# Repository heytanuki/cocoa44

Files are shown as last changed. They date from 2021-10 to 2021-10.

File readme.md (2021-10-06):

# 44% Cocoa

A choc-spaced, splittable 40 with hazard stripes across the top.

The 44% Cocoa was designed and sized to be under the 100mm^2 limit for free fabrication thru Allpcb. It is a little wider than 100mm wide, but that didn't seem to affect it being free!

### One small issue...

This has mounting holes directly under the top-left and top-right switches. What that means is that likely you will need to either use countersunk screws on those holes (the kind that have a conical head shape that's wider at the top), or change the size of the board to move those holes out to the side.

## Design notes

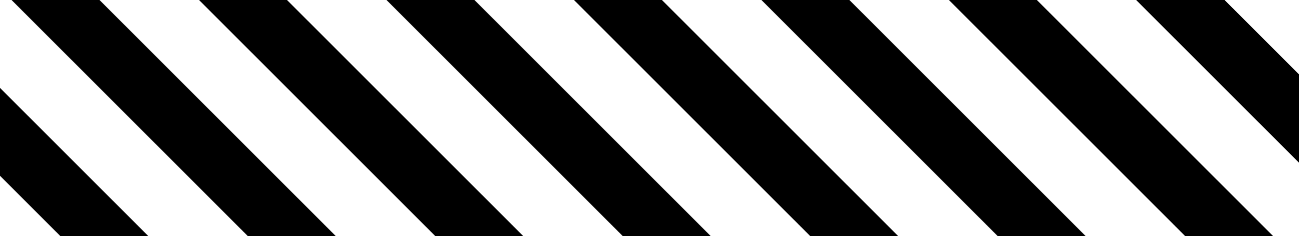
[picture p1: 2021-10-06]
top_stripes.png

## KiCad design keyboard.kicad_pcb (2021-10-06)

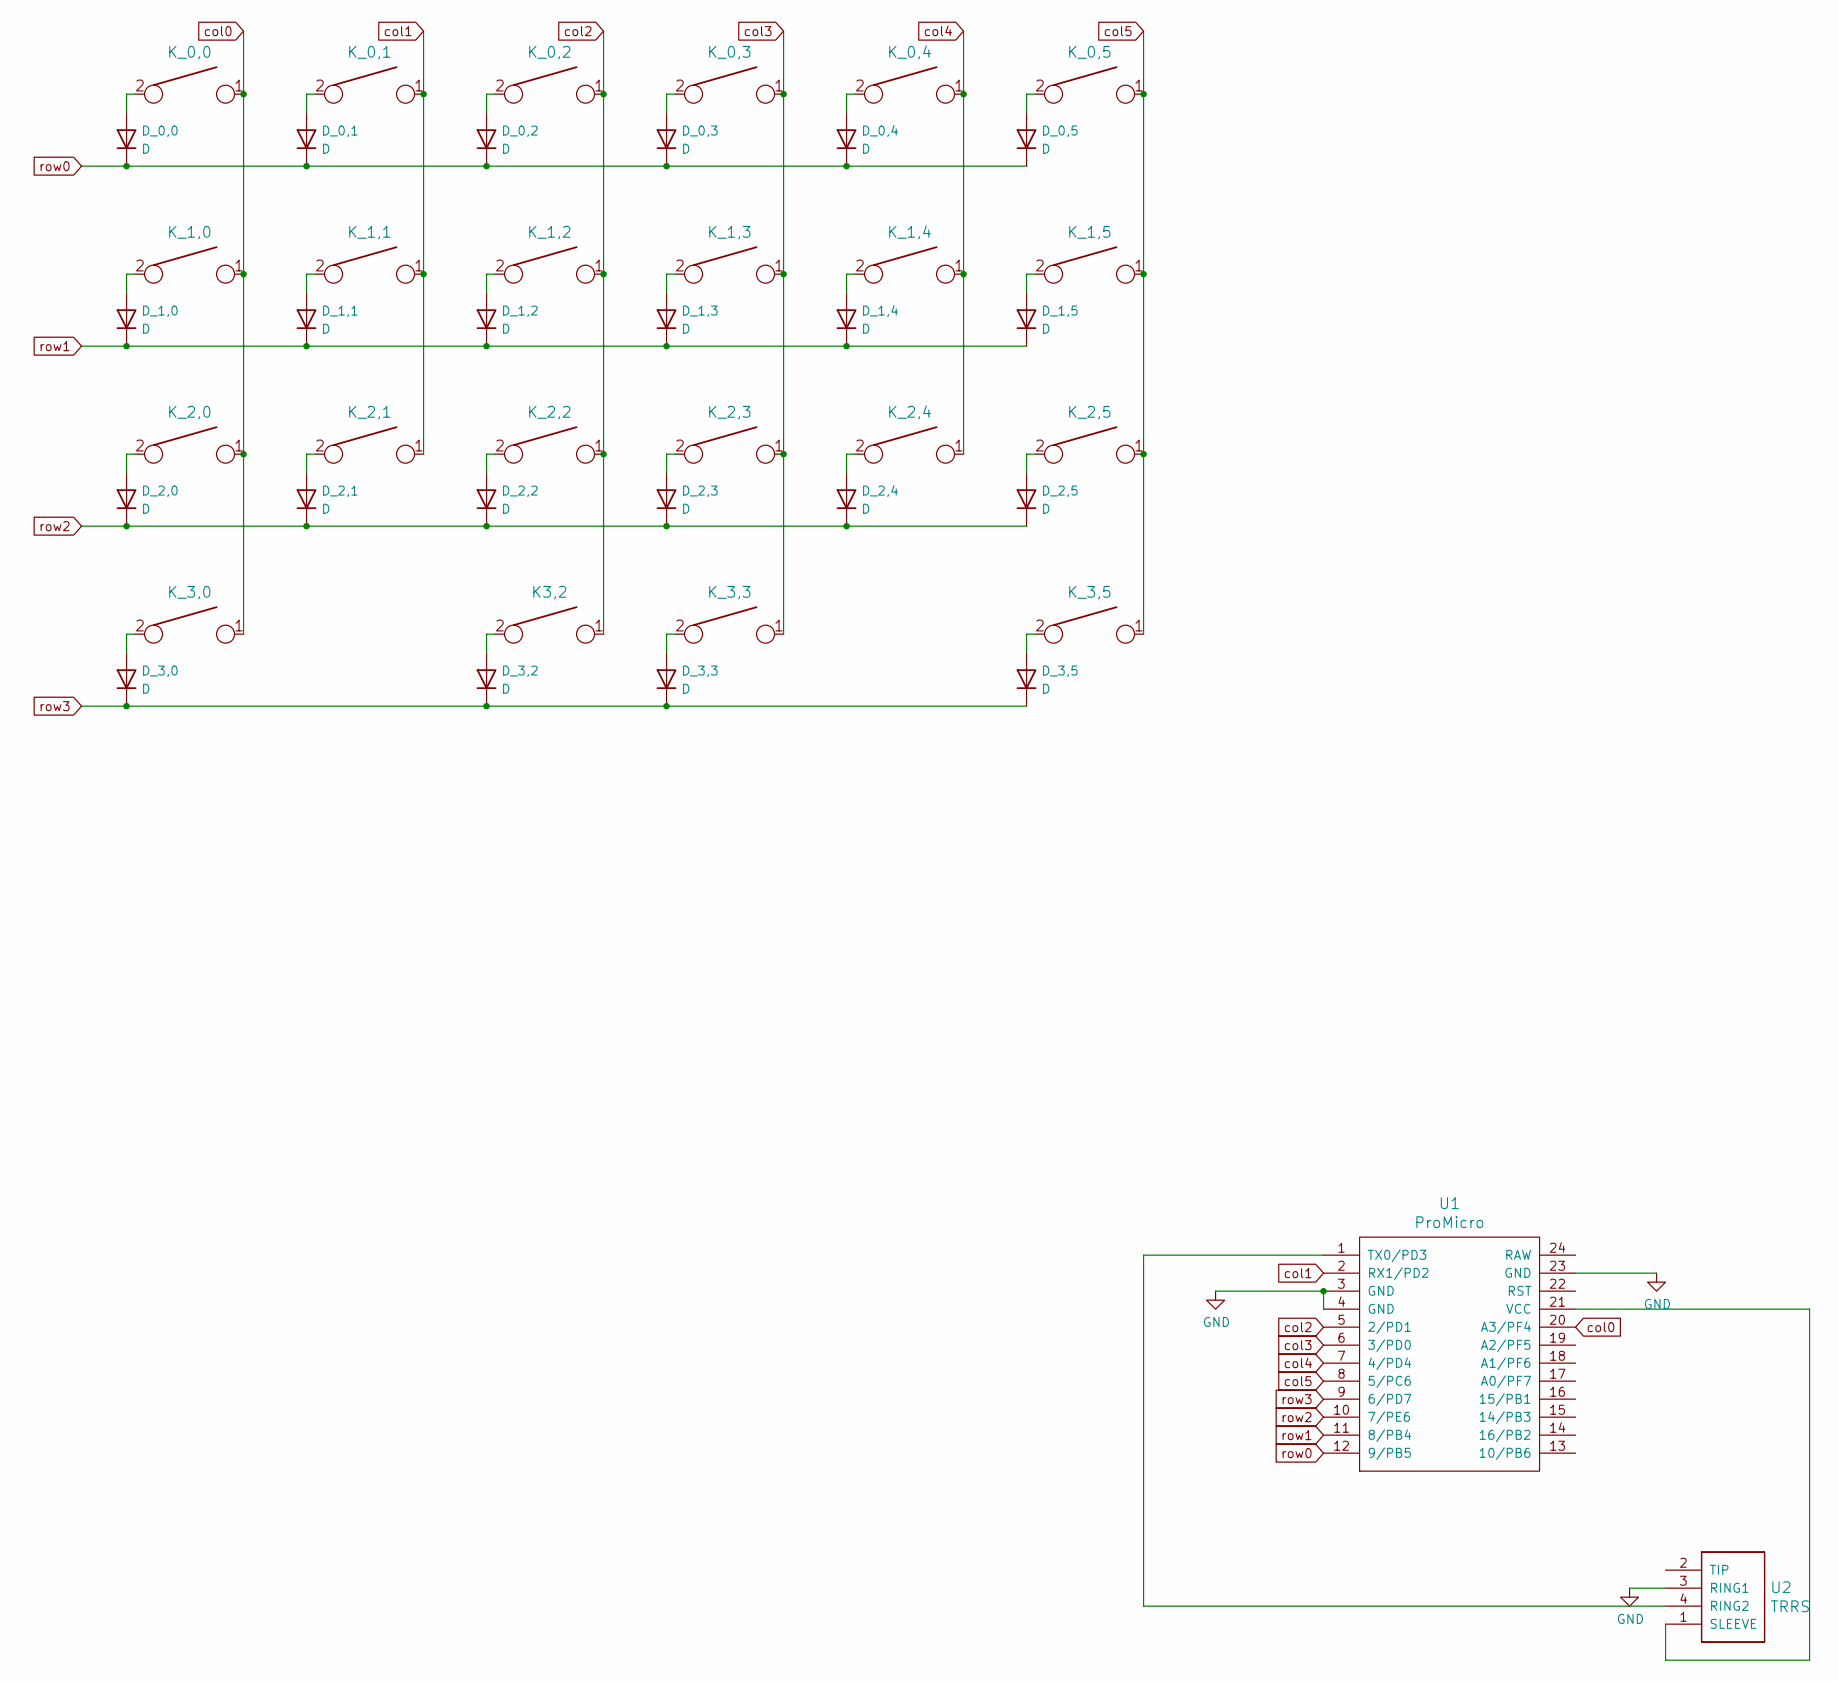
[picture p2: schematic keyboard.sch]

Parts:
D_0,0, D_0,1, D_0,2, D_0,3, D_0,4, D_0,5, D_1,0, D_1,1, D_1,2, D_1,3, D_1,4, D_1,5, D_2,0, D_2,1, D_2,2, D_2,3, D_2,4, D_2,5, D_3,0, D_3,2, D_3,3, D_3,5: D; D_SOD123_axial
K3,2: KEYSW; Choc-1u
K_0,0, K_0,1, K_0,2, K_0,3, K_0,4, K_0,5, K_1,0, K_1,1, K_1,2, K_1,3, K_1,4, K_1,5, K_2,0, K_2,1, K_2,2, K_2,3, K_2,4, K_2,5, K_3,3: KEYSW; Choc-1u
K_3,0, K_3,5: KEYSW; Choc-2u
U1: ProMicro; ArduinoProMicro
U2: TRRS; TRRS-PJ-320A

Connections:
GND: U1.3 (GND), U1.4 (GND), U1.23 (GND), U2.3 (RING1)
unnamed: D_0,0.2 (A), K_0,0.2
unnamed: D_0,1.2 (A), K_0,1.2
unnamed: D_0,2.2 (A), K_0,2.2
unnamed: D_0,3.2 (A), K_0,3.2
unnamed: D_0,4.2 (A), K_0,4.2
unnamed: D_0,5.2 (A), K_0,5.2
unnamed: D_1,0.2 (A), K_1,0.2
unnamed: D_1,1.2 (A), K_1,1.2
unnamed: D_1,2.2 (A), K_1,2.2
unnamed: D_1,3.2 (A), K_1,3.2
unnamed: D_1,4.2 (A), K_1,4.2
unnamed: D_1,5.2 (A), K_1,5.2
unnamed: D_2,0.2 (A), K_2,0.2
unnamed: D_2,1.2 (A), K_2,1.2
unnamed: D_2,2.2 (A), K_2,2.2
unnamed: D_2,3.2 (A), K_2,3.2
unnamed: D_2,4.2 (A), K_2,4.2
unnamed: D_2,5.2 (A), K_2,5.2
unnamed: D_3,0.2 (A), K_3,0.2
unnamed: D_3,2.2 (A), K3,2.2
unnamed: D_3,3.2 (A), K_3,3.2
unnamed: D_3,5.2 (A), K_3,5.2
unnamed: U1.1 (TX0/PD3), U2.4 (RING2)
unnamed: U1.21 (VCC), U2.1 (SLEEVE)
col0: K_0,0.1, K_1,0.1, K_2,0.1, K_3,0.1, U1.20 (A3/PF4)
col1: K_0,1.1, K_1,1.1, K_2,1.1, U1.2 (RX1/PD2)
col2: K3,2.1, K_0,2.1, K_1,2.1, K_2,2.1, U1.5 (2/PD1)
col3: K_0,3.1, K_1,3.1, K_2,3.1, K_3,3.1, U1.6 (3/PD0)
col4: K_0,4.1, K_1,4.1, K_2,4.1, U1.7 (4/PD4)
col5: K_0,5.1, K_1,5.1, K_2,5.1, K_3,5.1, U1.8 (5/PC6)
row0: D_0,0.1 (K), D_0,1.1 (K), D_0,2.1 (K), D_0,3.1 (K), D_0,4.1 (K), D_0,5.1 (K), U1.12 (9/PB5)
row1: D_1,0.1 (K), D_1,1.1 (K), D_1,2.1 (K), D_1,3.1 (K), D_1,4.1 (K), D_1,5.1 (K), U1.11 (8/PB4)
row2: D_2,0.1 (K), D_2,1.1 (K), D_2,2.1 (K), D_2,3.1 (K), D_2,4.1 (K), D_2,5.1 (K), U1.10 (7/PE6)
row3: D_3,0.1 (K), D_3,2.1 (K), D_3,3.1 (K), D_3,5.1 (K), U1.9 (6/PD7)

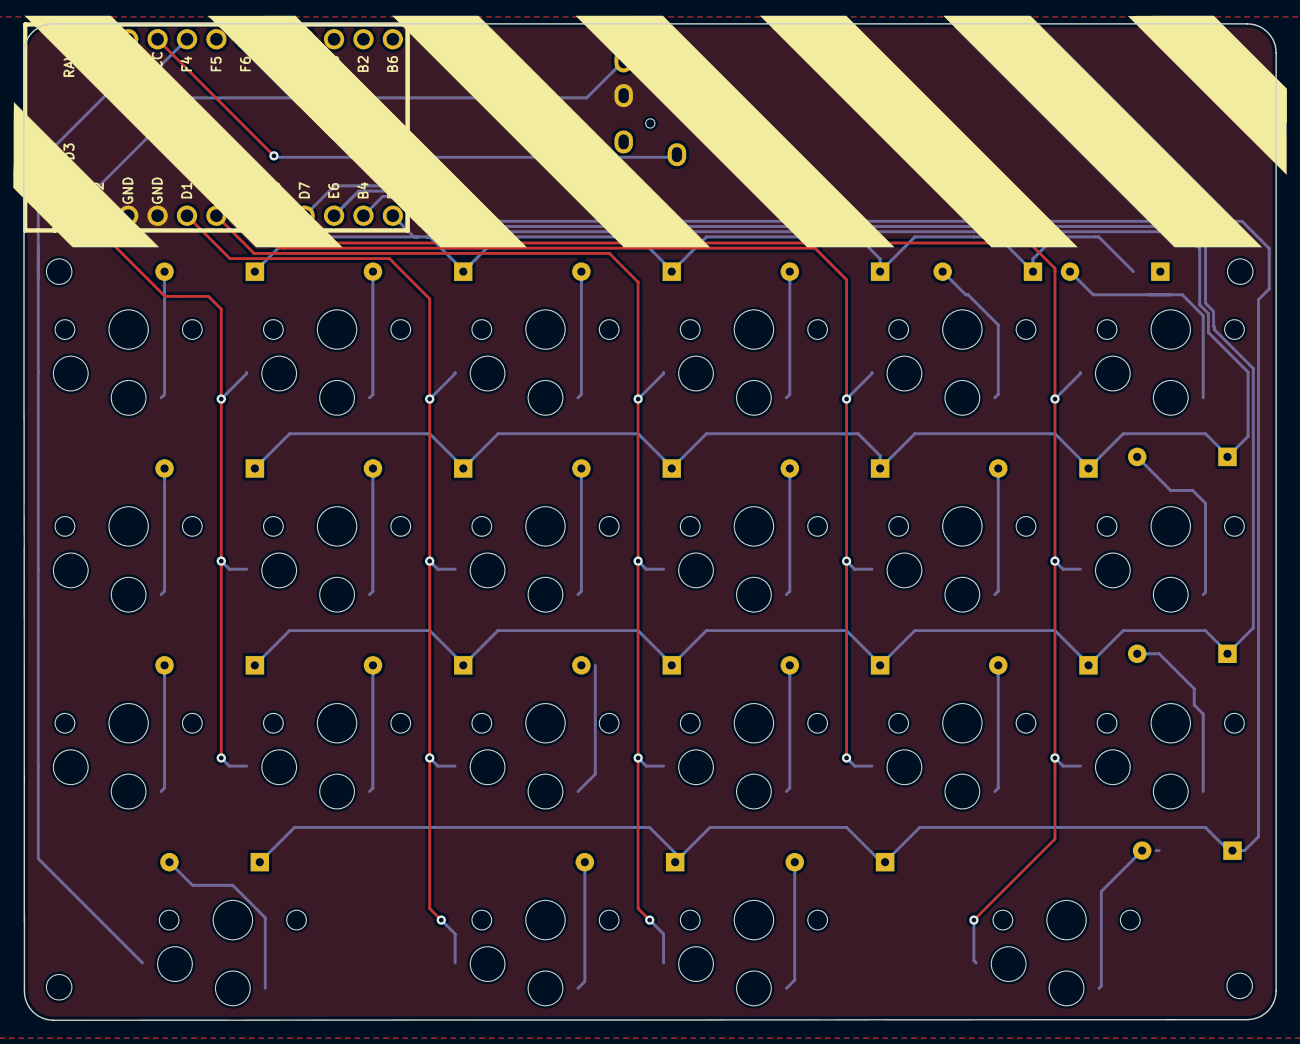
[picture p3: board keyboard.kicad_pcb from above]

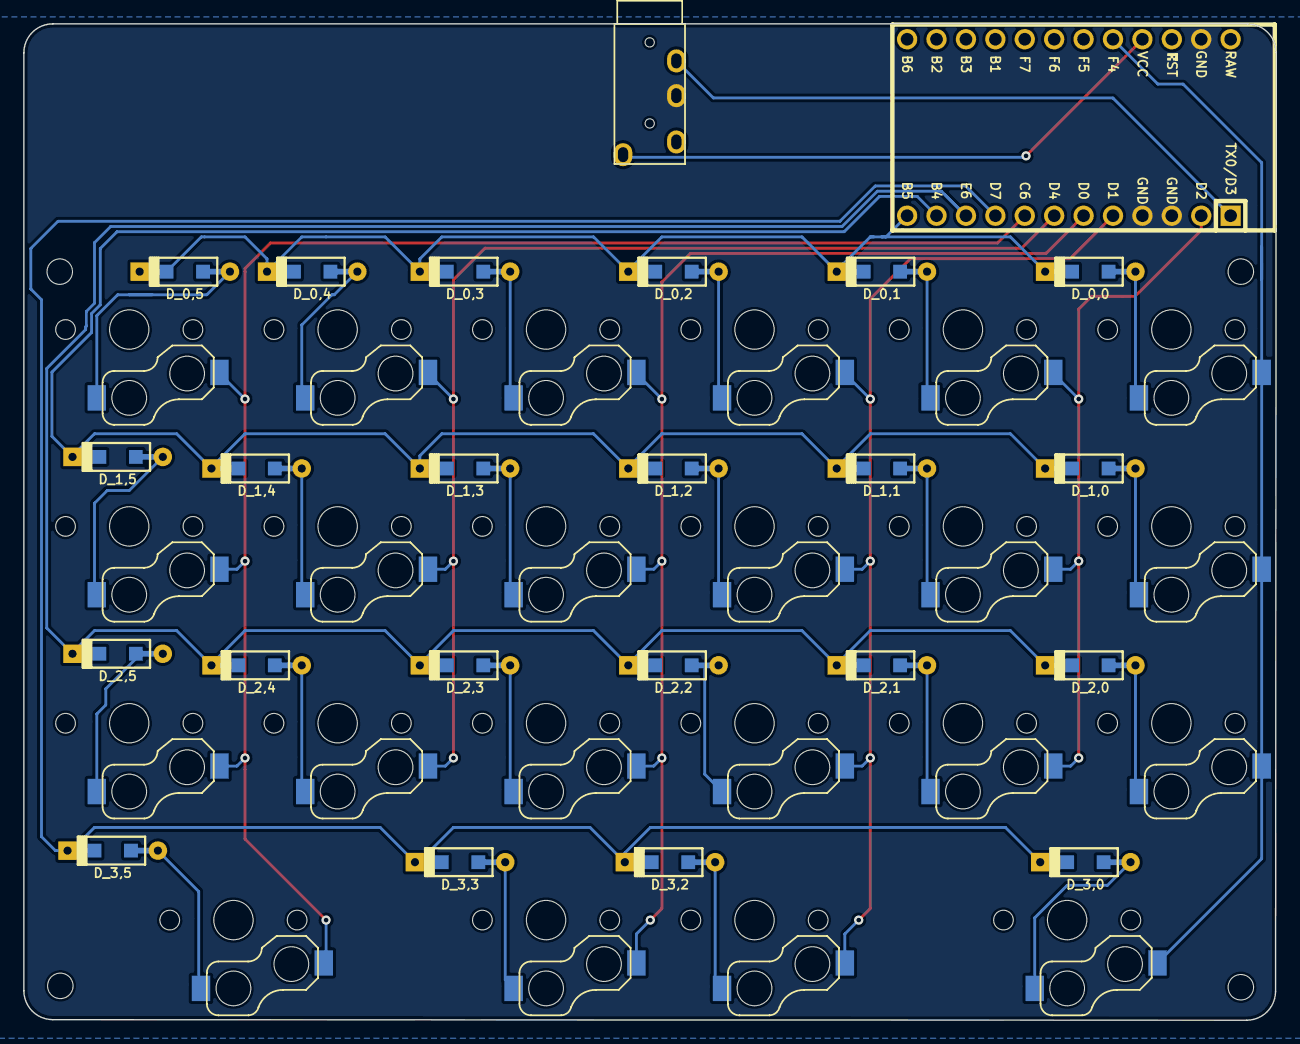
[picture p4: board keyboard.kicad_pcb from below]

Board: 2 copper layers, 108.1 x 86.1 mm, 46 parts (23 on the bottom side), 35 nets.

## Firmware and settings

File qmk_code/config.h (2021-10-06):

/*
Copyright 2021 Astra Jones

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
You should have received a copy of the GNU General Public License
along with this program.  If not, see <http://www.gnu.org/licenses/>.
*/

#pragma once

#include "config_common.h"

/* USB Device descriptor parameter */
#define VENDOR_ID       0x2605
#define PRODUCT_ID      0x44CC
#define DEVICE_VER      0x0002
#define MANUFACTURER    Star Boards
#define PRODUCT         44% Cocoa
#define DESCRIPTION     40 ortho split with choc spacing
#define VIAL_KEYBOARD_UID {0xF5, 0xF7, 0xCC, 0xD4, 0xEE, 0xED, 0x00, 0x1D}
 
/* key matrix size */
#define MATRIX_ROWS 8
#define MATRIX_COLS 6

#define SOFT_SERIAL_PIN D3
#define SPLIT_USB_DETECT

/*
 * Keyboard Matrix Assignments
 *
 * Change this to how you wired your keyboard
 * COLS: AVR pins used for columns, left to right
 * ROWS: AVR pins used for rows, top to bottom
 * DIODE_DIRECTION: COL2ROW = COL = Anode (+), ROW = Cathode (-, marked on diode)
 *                  ROW2COL = ROW = Anode (+), COL = Cathode (-, marked on diode)
 *
*//////////////////
#define MATRIX_ROW_PINS { B5, B4, E6, D7 }
#define MATRIX_COL_PINS { F4, D2, D1, D0, D4, C6 }

/* COL2ROW, ROW2COL*/
#define DIODE_DIRECTION COL2ROW

/* Debounce reduces chatter (unintended double-presses) - set 0 if debouncing is not needed */
#define DEBOUNCE 5

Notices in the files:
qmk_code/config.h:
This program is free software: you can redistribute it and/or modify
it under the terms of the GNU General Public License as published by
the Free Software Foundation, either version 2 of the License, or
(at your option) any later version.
